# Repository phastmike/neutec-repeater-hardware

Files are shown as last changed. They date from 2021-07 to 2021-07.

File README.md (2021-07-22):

# Guia do projecto Repetidor Neutec

Este documento visa guiar e documentar o projecto Repetidor Neutec.

## Enquadramento

O projecto surge de um contacto informal do Costa (**CT1EYN**) comigo
(**CT1ENQ**), cujo objectivo inicial seria documentar a parte de controlo que o
Costa (**CT4QC**) fez no repetidor de UHF de Guimarães para posteriormente as 
aplicar num repetidor de origem da Neutec que não cumpria os requisitos legais.

Quando referimos o Costa (**CT4QC**), também devemos incluir o Armindo
(**CT1AND**) e outros que eventualmente tenham participado no esforço de munir a
ARM (Associação de Rádioamadores do Minho) de um conjunto de repetidores de
"construção caseira".

Como não privei nem tive grande contacto com os membros da ARM desse período,
além de ter estado ausente da região por vários anos, acabo por desconhecer a
história dos bastidores técnicos da associação. Entretanto, infelizmente, quem 
detinha o conhecimento acabou por falecer (sk).

### Um pouco de história

Através de um documento anexo ao repetidor de Guimarães conseguimos apurar a
data de Setembro 1998 pelo que terá sido por essa altura que o repetidor estaria
pronto para ser instalado. Este repetidor era um rádio Neutec SM-1630U (UHF)
modificado para servir como repetidor. O emissor e receptor funcionam em
simultâneo e essa modificação não foi documentada, nem na altura, nem agora.
Também foi introduzida alguma electrónica para controlo de transmissão, 
identificação em morse com intervalo de 10 minutos entre outros.
Posteriormente, teve nova intervenção para cumprir os novos requisitos de
identificação de voz. Estas adições são o alvo da nossa documentação.

Inicialmente o indicativo do repetidor era **CT0UGM** na frequência de 
**439.100 MHz**, RU88, e com a alteração da legislação, passou a ter o
indicativo **CQ0UGMR**, RU728, até aos dias de hoje.

### O início do projecto

Volvidos estes anos todos e havendo no legado da ARM, um repetidor de origem da
Neutec (SM-1645HS) para os 2m (VHF), operacional mas sem tom de protecção e sem 
identificação, fazia todo o sentido perceber o que foi feito no repetidor de 
Guimarães e replicar, dentro das diferenças existentes, algo similar para dotar
a ARM de um repetidor que pudesse servir de substituto ou mesmo para uma nova
instalação. 

Havendo essa necessidade e com a pandemia que nos afectou desde 2019 até à
actualidade (estamos em 2021) houve um novo fôlego na comunidade de 
rádioaamadores e o Costa (**CT1EYN**) lançou o desafio que foi aceite.

Infelizmente só tivemos acesso ao repetidor Neutec já na fase final do projecto
pelo que haveria lugar a algumas melhorias adicionais, ainda assim, foi obtido
um bom resultado e estamos em testes finais faltando apenas os testes de campo
na montanha da Santa Marta, no local do repetidor.

## Requisitos

Legalmente, em Portugal, um repetidor para o serviço de amador deve cumprir um
conjunto de requisitos. Do ponto de vista de controlo, são os seguintes:

- Tempo de retransmissão - Timeout Timer: Max 3 min (180s)
- Tempo de penalização - Retrigger/Penalty: 5 seg.
- Intervalo de identificação - ID Interval: Max 10 min (600s)

Requisito adicional, será o de evitar que a identificação ocorra quando alguém
está a utilizar o repetidor evitando assim que duas vozes concorram pela atenção
. Além disso deve contemplar a utilização do microfone de mão, no próprio
repetidor e evitar que não haja identificação durante um período de bloqueio
("timeout"). Este requisito levanta uma questão em particular, a da
obrigatoriedade de se identificar de 10 em 10 minutos. No entanto, a lei deve,
na minha opinião, ser entendida ao invés de uma interpretação cega. Assim; 
do ponto de vista da nossa actividade, faz todo o sentido, identificar o
repetidor, intervaladamente, para que eventuais escutas,quando não haja 
actividade no repetidor, consigam identificar o mesmo.
Se a identificação ocorrer em simultâneo com um QSO, em nada será benéfico, 
tanto é que este requisito se coloca. Do ponto de vista informativo, a presença
de um QSO implica a identificação dos intervinientes que por sua vez identifica
indirectamente o repetidor que por sua vez aguardará de forma incessante, a
possibilidade de se identificar, se é que podemos dizê-lo desta forma. Se a 
identificação ocorre no primeiro instante em que está livre ou se após uma
análise mais ou menos cuidada, o resultado obtido, será sempre no intuito de
seguir a lei mas salvaguardando a "qualidade" de um qso.

## Primeira análise

O primeiro passo do projecto foi efectuar engenharia reversa nos circuitos de
controlo construídos pelo Costa (**CT4QC**) por forma a desenhar um esquema e
posterior compreensão dos passos dados na altura. 

O repetidor de Guimarães foi construído com montagem de superfície utilizando
componentes THT, com PCB cortados "à mão" e placas de furos genéricas. Além
disso, estão divididos em dois "conjuntos" que para simplicidade passaremos a
designar por:

- Placa de cima
- Placa de baixo

Esta designação tem em consideração o posicionamente dos circuitos na montagem
original que foi mantida.

### Placa de baixo

Na placa de baixo temos vários blocos:

- Detecção de sub-tom
- Controlo de PTT
- Temporização de cauda
- Temporização de retransmissão

### Placa de cima

Na placa de cima temos os blocos referentes à identificação:

- microcontrolador
 - temporizador de 10min.
 - verificação de tom e ou PTT
 - disparo da identificação Voz/Morse
- controlo de PTT da identificação
- gerador de sinal áudio de Morse

## Organização do projecto

Após esta breve explicação, convém descrever a organização da documentação
relativa ao projecto. 

O projecto é na realidade um conjunto de projectos:

- Desenho dos esquemas do repetidor original
- Novo projecto de repetidor baseado no anterior, inclui PCBs e novo *firmware*
- Adaptação do desenho original, no repetidor de Guimarães com as alterações
realizadas ao esquema inicial.
- Vários (documentos, *datasheets*, imagens, etc)

## Descrição detalhada

Segue uma descrição, mais detalhada, das várias pastas deste projecto.

### [CT1ENQ_CT1EYN](./CT1ENQ_CT1EYN/)

As novas placas, esquemas e firmware.

- [Placa de baixo](./CT1ENQ_CT1EYN/bottom)
- [Placa de cima](./CT1ENQ_CT1EYN/top)
- [Novo firmware e código fonte (AT89C2051)](./CT1ENQ_CT1EYN/firmware)
- [Manual](./CT1ENQ_CT1EYN/manual)

### [CT4QC](./CT4QC)

O esquema original das adições que foram feitas ao SM-1630U para o dotar de
controlo de repetidor (baseado no repetidor de UHF de Guimarães). Também inclui
os esquemas das alterações que foram feitas ao original e uma "imagem" do
código original (binário). O firmware para esta modificação está anexa ao
novo *firmware* do repetidor.

- [Esquema de baixo](./CT4QC/original/bottom)
- [Esquema de cima](./CT4QC/original/top)
- [Esquema das novas modificações (cima)](./CT4QC/mod/)
- [*Firmware* original do AT89C2051](./CT4QC/original/firmware)

#### [Tools](./tools)

Programas auxiliares para cálculo de valores no temporizador e detector de tom.
Contém tabelas de valores em pdf.

#### [Doc](./doc/)
  
Conjunto de documentos reunidos durante o desenrolar do projecto, uns mais
relevantes do que outros (Datasheets, Papers, Pdfs, etc).

**Esta pasta não deverá estar presente nos repositórios públicos**.

#### [Images](./images/)

Imagens relacionadas com o projecto.

**Esta pasta não deverá estar presente nos repositórios públicos**.

#### [Sound](./sound/)

Ficheiros de áudio, utilizados no projecto (identificação).

## Software, *Frameworks* e outras informações

O trabalho foi projectado na sua totalidade num sistema Linux (Fedora 34) no
entanto existem as mesmas ferramentas ou equivalentes para o sistema Windows.

No desenho de esquemas e placas de circuito impresso, foi utilizado o
software gratuito, [KiCad 5.1.10-1](https://www.kicad.org).

O firmware foi desenvolvido em linguagem C e foi utilizado o compilador **sdcc**
, [Small Devices C Compiler](http://sdcc.sourceforge.net/) (v4.0.0) juntamente
com **Makefiles**.

Para programar o microcontrolador AT89C2051, utilizamos o programador
[TL866II Plus](http://www.autoelectric.cn/en/tl866_main.html) e o programa
[**minipro** (linux)](https://gitlab.com/DavidGriffith/minipro/).

## Notas finais

Os projectos devem ter documentos descritivos dentro de cada pasta, sempre que
se justificar.

Também convém indicar que o projecto de firmare (código fonte), quando num
contexto de repositório público, terá o seu repositório próprio. Já os esquemas
e restantes ficheiros estarão a acompanhar este documento. Num contexto interno
à ARM ou da comunidade de rádioamadores local, os ficheiros estarão todos 
agregados, num formato de compressão comum.

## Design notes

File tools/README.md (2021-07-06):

# Tools

Simple programs to list values for timeout timer and ctcss circuits.

## Folders

- bin

 contains the binary files to execute

- src
  
 contains the c source code

- doc

  contains a simple processed output to generate the pdf files via pandoc

## Notes

Check the Makefile content.

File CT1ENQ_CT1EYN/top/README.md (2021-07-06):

# Neutec Repetidor/Repeater

## PCB Assembly and fitting notes

After assembly, Costa's 555 (Motorola) was erratic at best (bad pin connection?). Changed it for a Philips one and problem solved. Repeater was not ungrabbing the PTT line at the end of transmition (id). The PTT sense circuit is very sensible. Adding a 100nf/10nf capacitor at the main J connector (8 pin molex) pin1 (ID_PTT) did improve the result. Also the ISD play auto ptt key up saw the 100uf removed. Probably it's not even needed or if added then a lower value, eventually a ceramic cap would suffice.

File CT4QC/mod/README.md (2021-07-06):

# Repeater Modification

The goal of this document is to describe the modification of the original circuit,
from CT4QC, to include the new desired behaviour introduced by CT1ENQ and CT1EYN.

This new behaviour features:

- Ability to disabled repeater identification (ID),
- Ability to select between Voice ID, Morse ID or no ID (as indicated above),
- Inhibit ID if repeater is in use.

Portuguese law requires that the repeaters have a voice id, every 10 minutes, 
a maximum timeout of 3 minutes (180 seconds) and a 5 seconds retrigger time.

There are various steps which can be followed that will achieve the same result, but
one thing is known,a new firmware must be flashed so we that we have more flexibility
and control.

## Limitations

As we will not build any hardware we must inherit some decisions like:

- ID Trigger not as reset but as input on pin 11 (P3.7)
- XTAL could be changed but lets consider the installed 4MHz.
- PCB is generic so we have limited in space (Keep it simple).

## Cenarios

### Cenario 1

Keep it simple, ignore morse code, avoid connecting/messing the 555 and to avoid
id, simple add a jumper for **`ToneDetector_ID_PTT`** when connecting to the bottom
board.

Also add a diode to NE567 output (pin 8) and check repeater use (common to all
scenarios).

This approach is very simple and is almost a crime not to do a little better if we are
messing with the repeater this deep.

### Cenario 2

Done is good, well done is much better. Add two jumpers (2 bit binary) to have a 4
option combination for ID. eg:

- Both, either one or none

**Optionally** add another jumper for long or short morse id:

- Short is just callsign **(`"de CQ0VBRG"`)**
- Long is Callsign + QTH Locator **(`"de CQ0VBRG IN51MT"`)**

Add a diode to NE567 output (pin 8) and check repeater use.

**A small shorcut is to avoid the long/short morse selection and simply reprogram the
controller if a new message is desired.**

## Changes

Changes to be preformed for **cenario 2**:

1. Remove ground (GND) from pin 19 (P1.7)
 - This pin controls morse id w/o QTH Locator (Short/Long).
 - Convert this or other pin to a jumper to allow selection of long vs short morse id
- New output pin for voice id trigger (ISD_PLAY) (pin 17).
- Resolder NE555 VCC jumper wire (is cut).
- Resolder Morse ID Audio wire (is cut).
- Add 2 jumpers for id type (Morse/CW)
- Add the diode to a input pin. Test connection to NE567 vs ToneDetector opencolector.

These changes are shown in the new schematic for this modification.

The new firmware is also supplied as source code and check the documentation of this
project for more details.

## Work done

On June 3, 2021 we (ct1enq and ct1eyn) preformed the change. The reset button was left
untouched and does not have any function associated. May add that in a future firmware.
Also, no long/short morse ID. The morse volume pot. may need to be changed (rusty?).
The algorithm for repeater use vs ID ~~should~~ was be improved.

## Document

This document is dated from May 2021. Written by CT1ENQ (callsign at gmail for email).

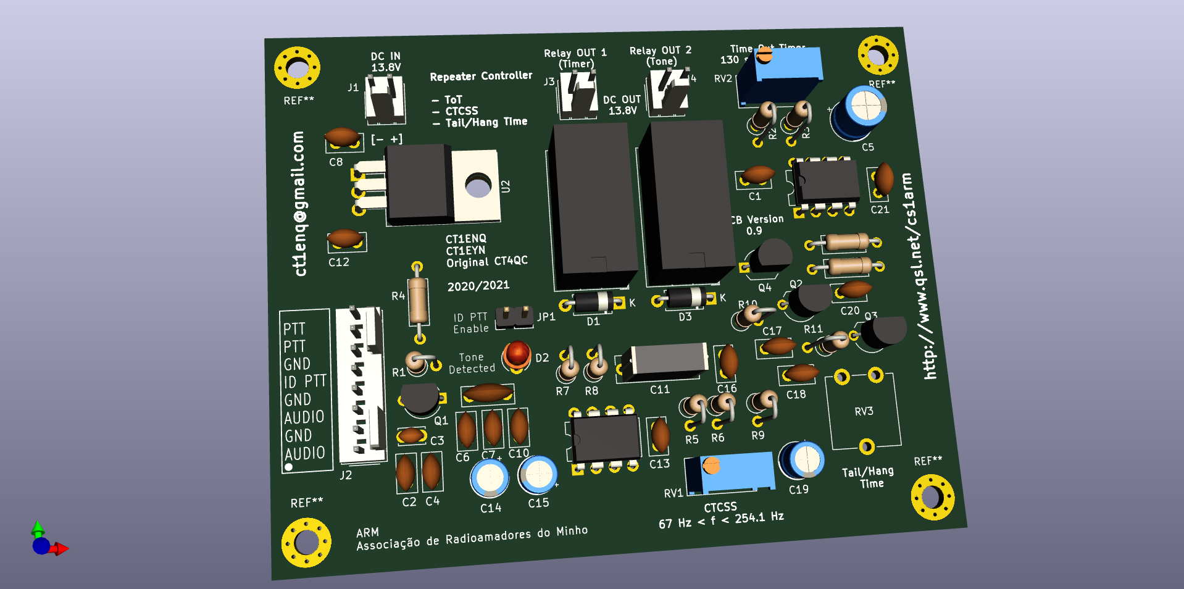
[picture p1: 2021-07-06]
CT1ENQ_CT1EYN/bottom/Export/0.9/RepeaterController3D_V0.9.png

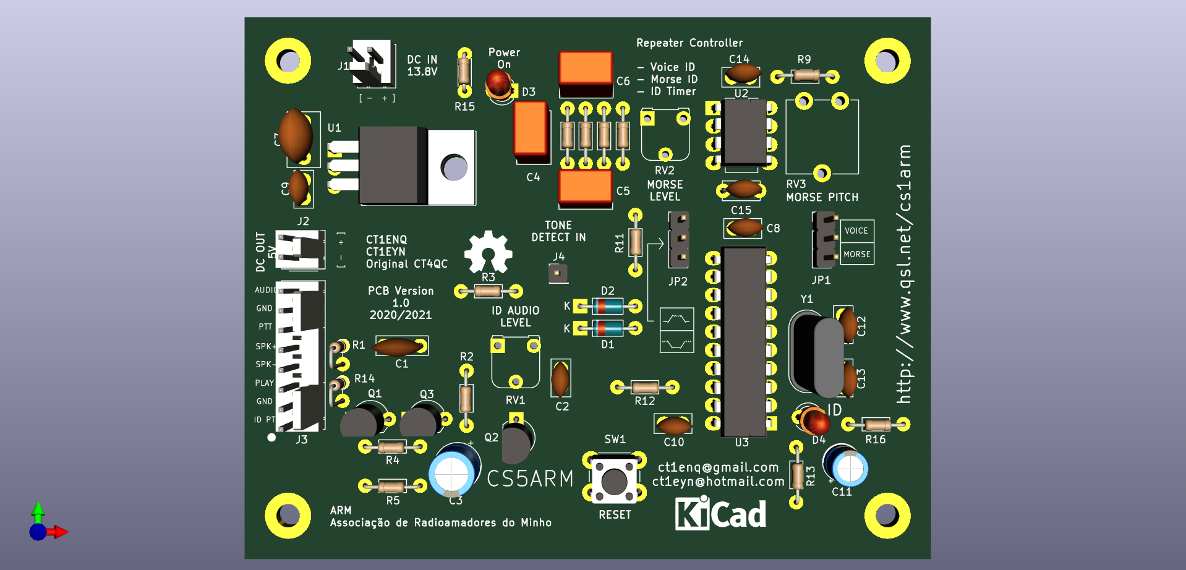
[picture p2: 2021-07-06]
CT1ENQ_CT1EYN/top/Export/1.0/beta/RepeaterController_3d_3.png

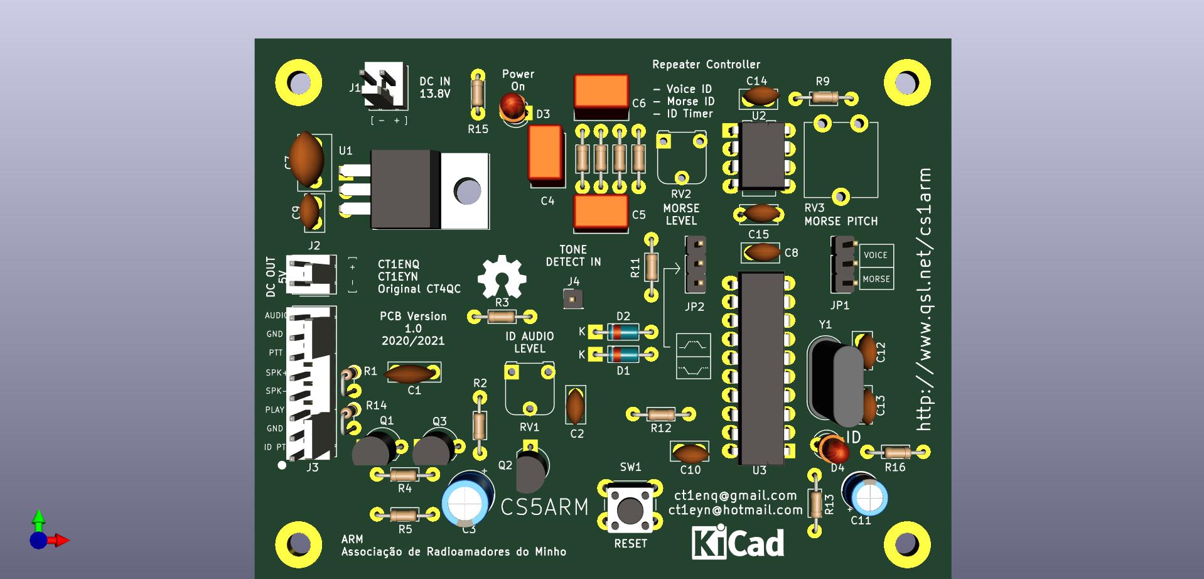
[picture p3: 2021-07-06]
CT1ENQ_CT1EYN/top/Export/1.0/beta/RepeaterController_3d_3.jpg

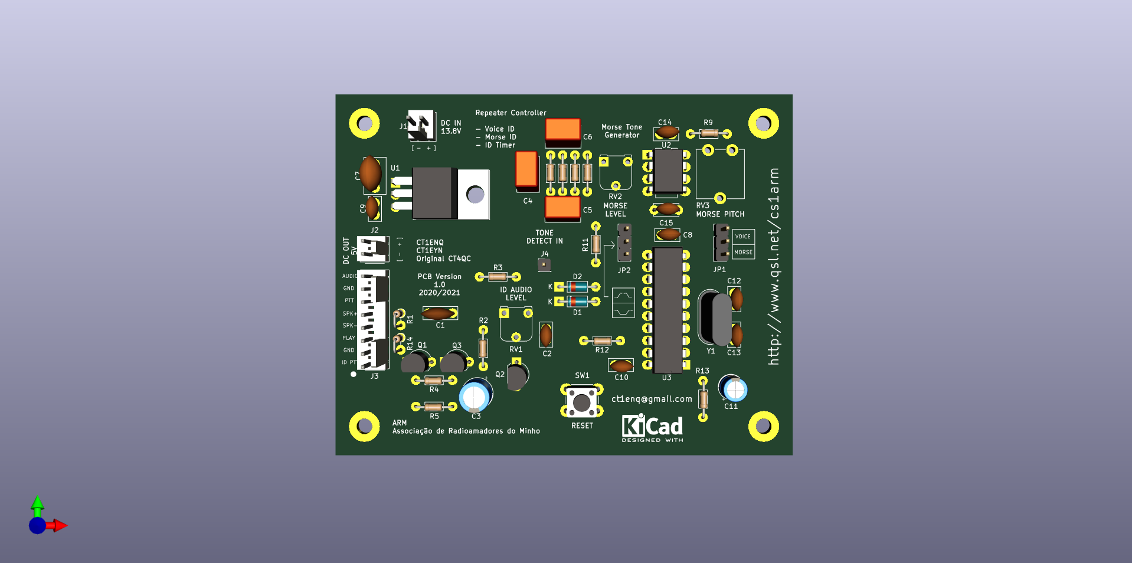
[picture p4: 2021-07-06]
CT1ENQ_CT1EYN/top/Export/1.0/alfa/RepeaterController_3d_1.png

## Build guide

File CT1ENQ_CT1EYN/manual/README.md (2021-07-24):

# Manual Repetidor Neutec SM-1645HS

Pequeno manual das novas funcionalidades e alterações efectuadas ao repetidor
Neutec.

## Placa de baixo

Situada na parte inferior do rádio, a placa de baixo contém o circuito de 
detecção de tom CTCSS (U3), temporizador de *timeout* (U1) e controlo de tempo
de "cauda".

Imagem com identificação das partes a explicar:

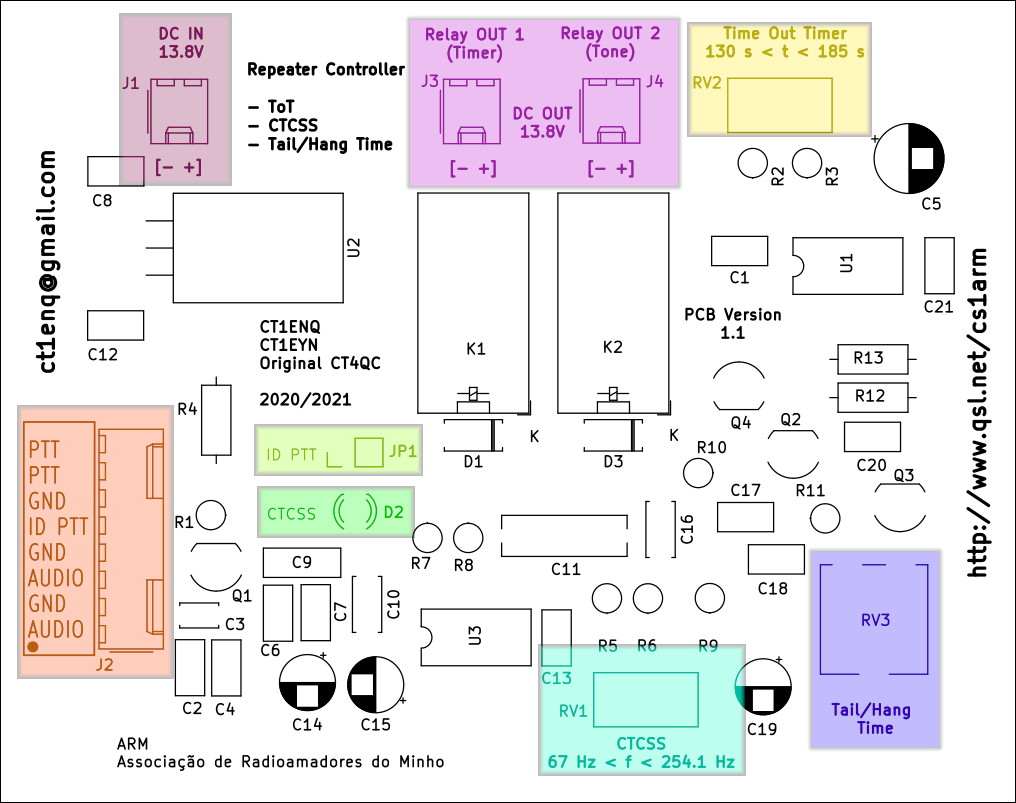
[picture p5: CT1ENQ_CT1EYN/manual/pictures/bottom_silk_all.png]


- **J1**: Alimentação 13.8V (Entrada).
- **J2**: Conjunto de 8 ligações (pino 1 com circulo preto):
 - **8** - **PTT**: Entrada/Saída de PTT
 - **7** - **PTT**: Entrada/Saída de PTT
 - **6** - **GND**: Massa
 - **5** - **ID PTT**: Entrada PTT placa de identificação (ID PTT)
 - **4** - **GND**: Massa
 - **3** - **AUDIO**: Entrada áudio
 - **2** - **GND**: Massa
 - **1** - **AUDIO**: Entrada de áudio
- **J3 e J4**: Saída de 13.8V para as ventoínhas.
 - **J3**: acompanha retransmissão (desliga com *timeout*)
 - **J4**: acompanha presença de CTCSS (mesmo após *timeout*)
- **RV1**: Sintonia do tom CTCSS (afinado para **123 Hz**)
- **RV2**: Tempo de *timeout* (afinado para **180s = 3 min**)
- **RV3**: Tempo de cauda (pequeno ajuste; não se nota muito devido à cauda já 
existente)
- **D2**: Led indica detecção de tom CTCSS
- **JP1**: Se colocado, permite controlo de PTT através da placa de cima (ID).

Em J2, pinos 7 e 8, sinal de PTT, um é utilizado para ligar ao PTT do rádio
e o outro serve para enviar o sinal de PTT para a placa de cima. Os pinos 1 e 3
para entrada/saída de audio aplicavam-se no caso do repetidor de UHF. Aqui basta
utilizar um dos pinos.

## Placa de cima

Situada na parte superior do rádio, a placa de cima contém o circuito de 
identificação do repetidor, controlado por U3 (uC at89c2051). O sinal de áudio
de morse é gerado por U2 (555) e sinal de identificação de voz é gerado por
placa externa com IC da ISD (ISD1820).

Imagem com identificação das partes a explicar:

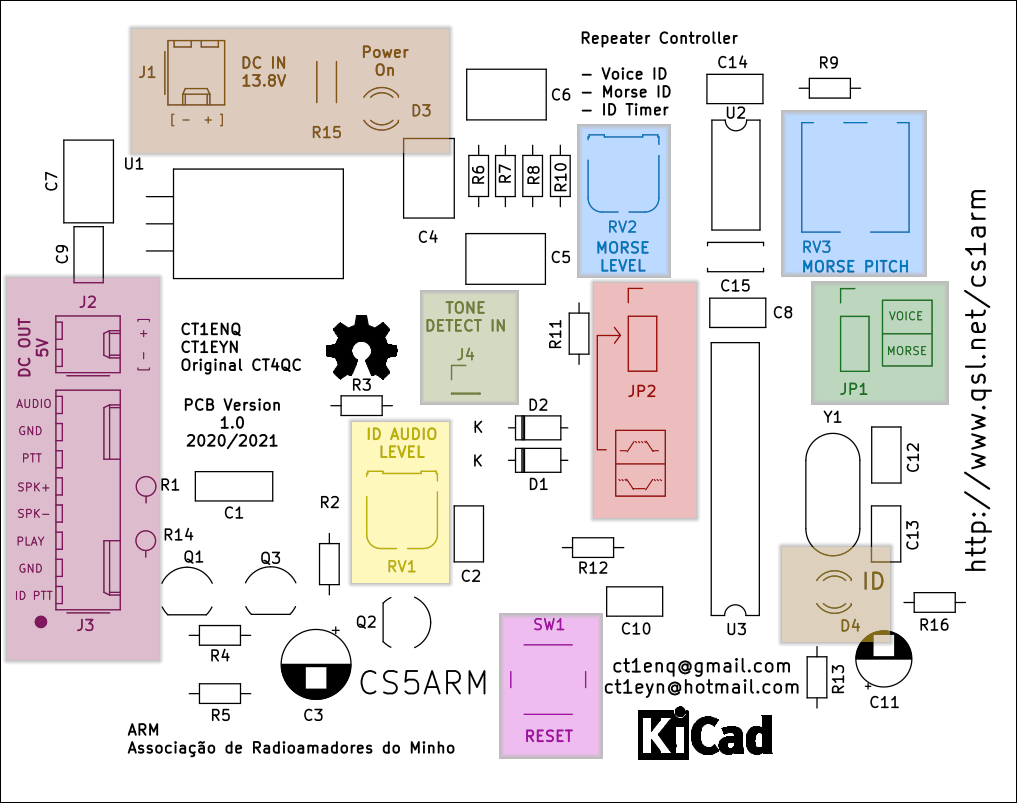
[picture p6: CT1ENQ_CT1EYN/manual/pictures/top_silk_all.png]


- **J1**: Alimentação 13.8V (Entrada)
- **J2**: Saída de 5V para placa de voz (ISD1820)
- **J3**: Conjunto de 8 ligações (pino 1 com círculo preto):
 - **8**: AUDIO: Saída de sinal de áudio, voz e morse
 - **7**: GND: Massa
 - **6**: PTT: Entrada sinal PTT para detectar presença de massa via díodo
 - **5**: SPK+: Entrada *Speaker+* (ISD1820)
 - **4**: SPK-: Entrada *Speaker-* (ISD1820)
 - **3**: PLAY: Saída de disparo/trigger *Play* (ISD1820)
 - **2**: GND: Massa
 - **1**: ID PTT: Saída para controlo PTT quando há identificação
- **J4**: Liga ao relé (Tone) para detectar presença de massa via díodo
- **D3**: Led indica alimentação na placa (depois do regulador U1)
- **D4**: Led para estado de identificação:
 - **Pisca** quando pretende identificar mas não tem jumper JP1 ligado (sem
 tipo de identificação definido)
 - **Ligado** quando está no período de pré identificação, a avaliar utilização
 do repetidor
- **RV3**: *Pitch*/Tom do sinal de morse
- **RV2**: Volume áudio do sinal de morse
- **RV1**: Volume áudio do sinal de Voz (ISD1820)
- **SW1**: *Reset*/Reiniciar microcontrolador
- **JP1**: Selecciona tipo de identificação áudio
 - **1-2** : Voz
 - **2-3** : Morse
- **JP2**: Seleciona tipo de disparo/trigger ISD
 - **1-2**: Transição 0 -> 5 V (Flanco ascendente) (*Default* ISD1820)
 - **2-3**: Transição 5 -> 0 V (Flanco descendente)

## Alterações ao original

O equipamento já era repetidor de origem, embora para tal, era necessário
colocar o *Squelch* no mínimo desligando o interruptor acoplado. O Costa (CT1EYN)
fez um *bypass* e agora **o rádio está sempre em modo repetidor**, 
independentemente da posição do *Squelch* (Indicado pelo Led ***Repeat***).

Dada a natureza do rádio, as alterações necessárias no próprio rádio foram
poucas e pouco intrusivas. Infelizmente o esquema não tinha referências para os
pinos da ficha *J701* (placa do receptor) e foi necessário efectuar esse 
trabalho, apresentado na imagem:

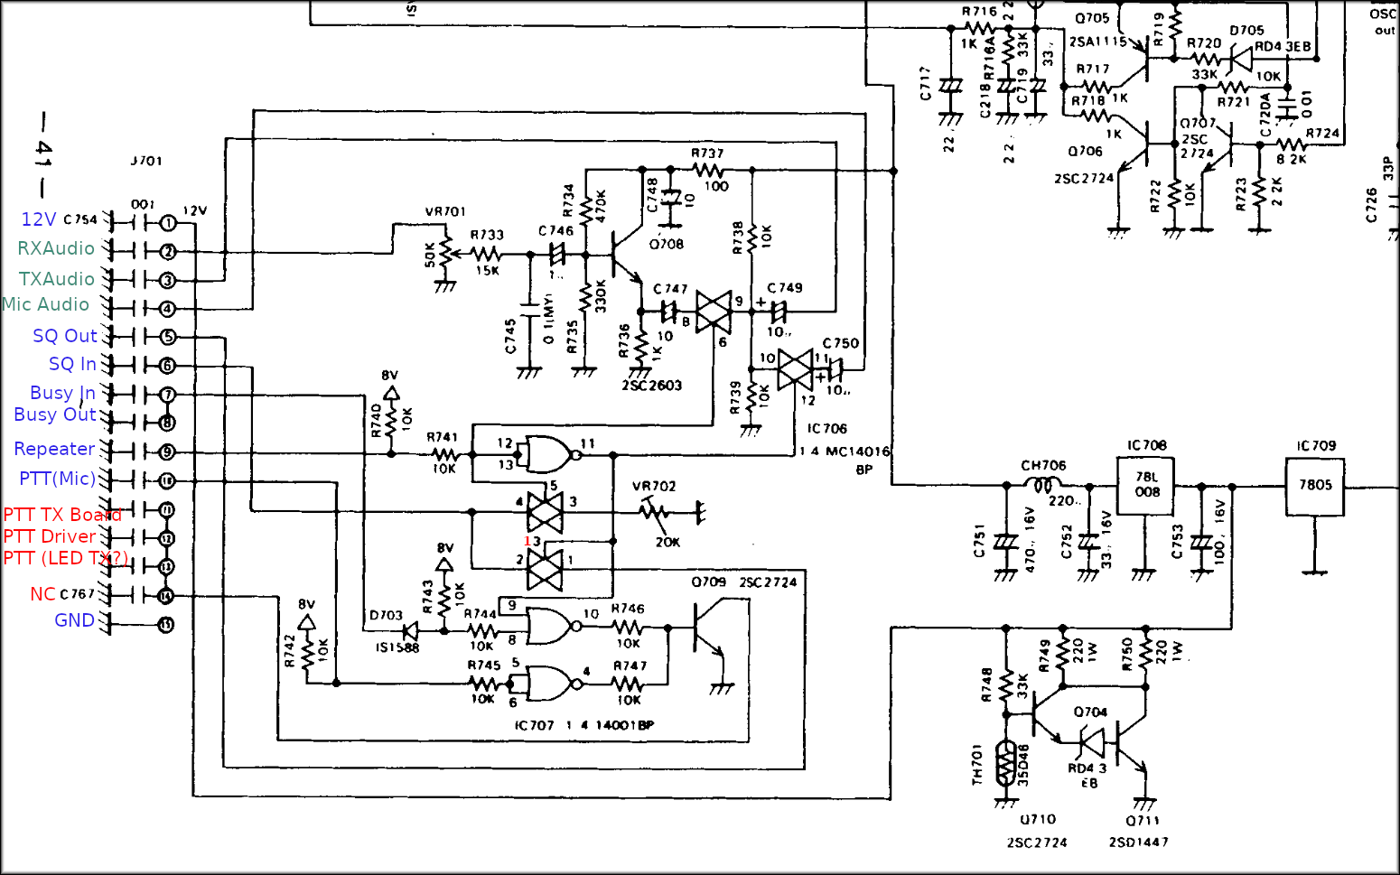
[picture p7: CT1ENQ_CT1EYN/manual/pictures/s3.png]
Neutec J701


Os pinos 11 a 13 (e 14 mas está sem ligação) são o sinal de PTT para o repetidor
original (cores: cinza, branco e azul). Os fios que ligavam a estes pinos, 
juntamente com o pino 10 (violeta - PTT do microfone de mão) foram
redirecionados para uma ficha de 4 pinos que passa a controlar o PTT através da
placa de baixo, representada na figura em baixo no ponto **A**.

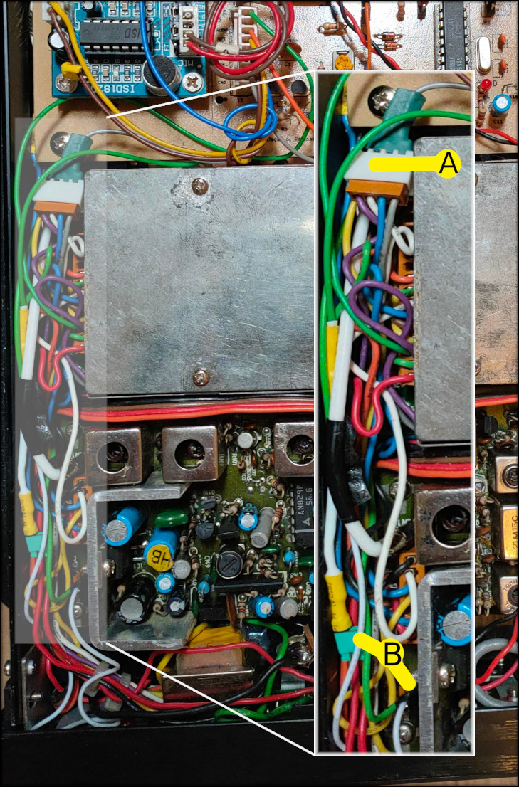
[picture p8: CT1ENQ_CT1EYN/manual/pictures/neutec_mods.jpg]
Neutec Mods


Em **B** está representado o ponto para ir buscar o sinal de áudio ao 
discriminador (J102) ou então ligar a um pino que foi preparado para utilizar a
saída do auscultador externo (com jumper verde), mas aqui o volume passa a
influenciar o sinal que vai para o detector de tom. Quando o sinal está ligado
a este ponto, o volume deve estar na posição indicada na figura:

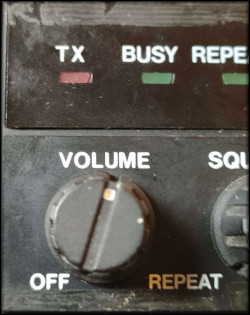
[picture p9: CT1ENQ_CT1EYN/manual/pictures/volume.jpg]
Neutec Volume


O J102 representado no esquema, é o sinal à saída do discriminador e é um
ligador de dois pinos ("*shuntados*").

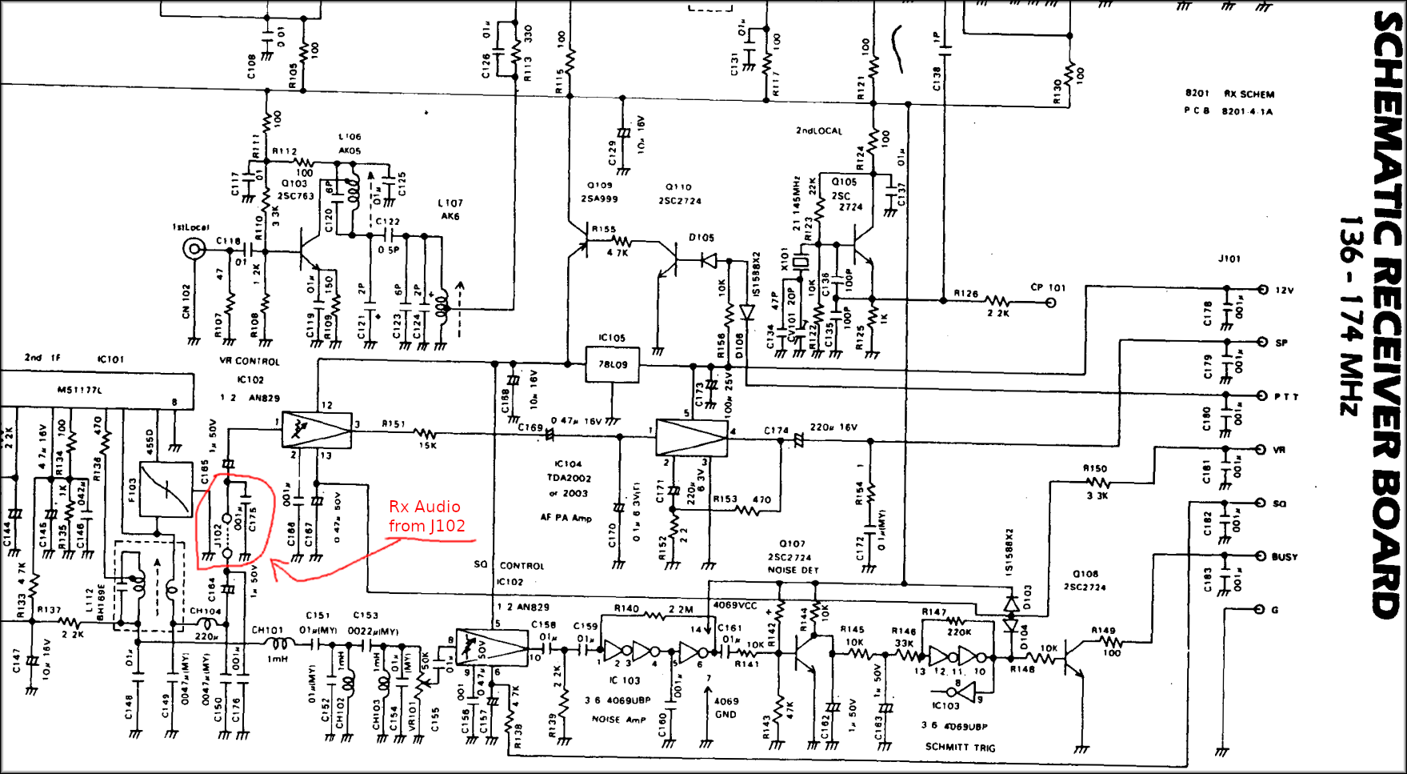
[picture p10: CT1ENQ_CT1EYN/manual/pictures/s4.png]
Neutec J102


O ideal seria utilizar este ponto e evitar a influência do controlo de volume,
no entanto, sinais fracos que nem abrem o limiar do squelch podem colocar o 
repetidor no ar.

## Imagens das placas cima/baixo

### Fundo/Baixo

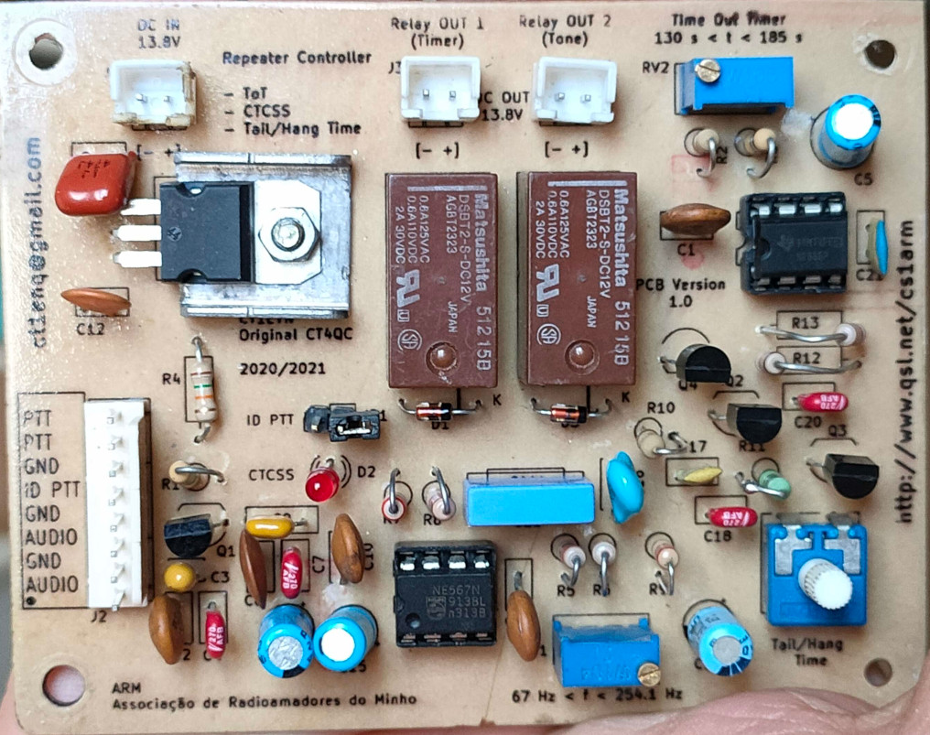
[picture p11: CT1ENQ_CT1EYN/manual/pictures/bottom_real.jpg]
Fundo


### Topo/Cima

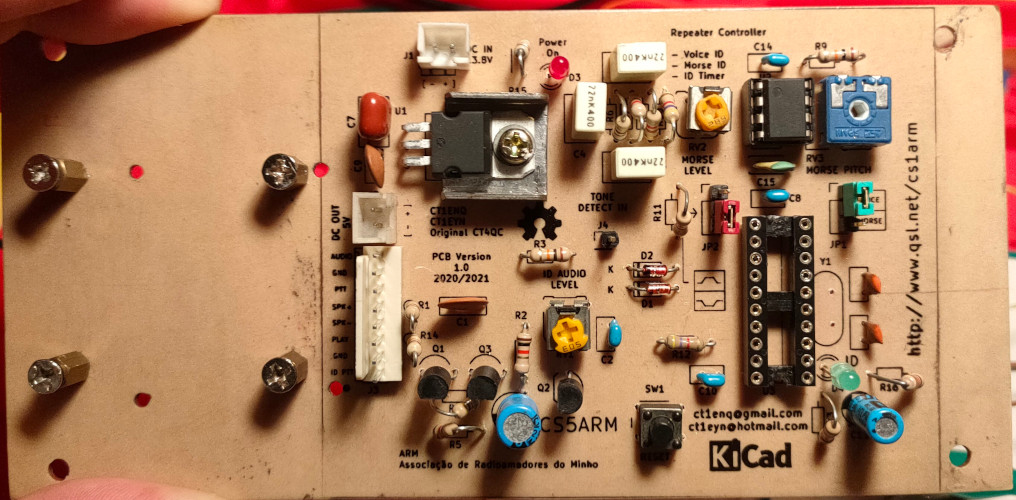
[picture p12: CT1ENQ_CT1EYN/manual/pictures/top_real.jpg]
Topo


## Créditos

2020/2021 Versão 1.1

- CT1ENQ (Miguel) ct1enq@gmail.com
- CT1EYN (Costa) ct1eyn@hotmail.com

##

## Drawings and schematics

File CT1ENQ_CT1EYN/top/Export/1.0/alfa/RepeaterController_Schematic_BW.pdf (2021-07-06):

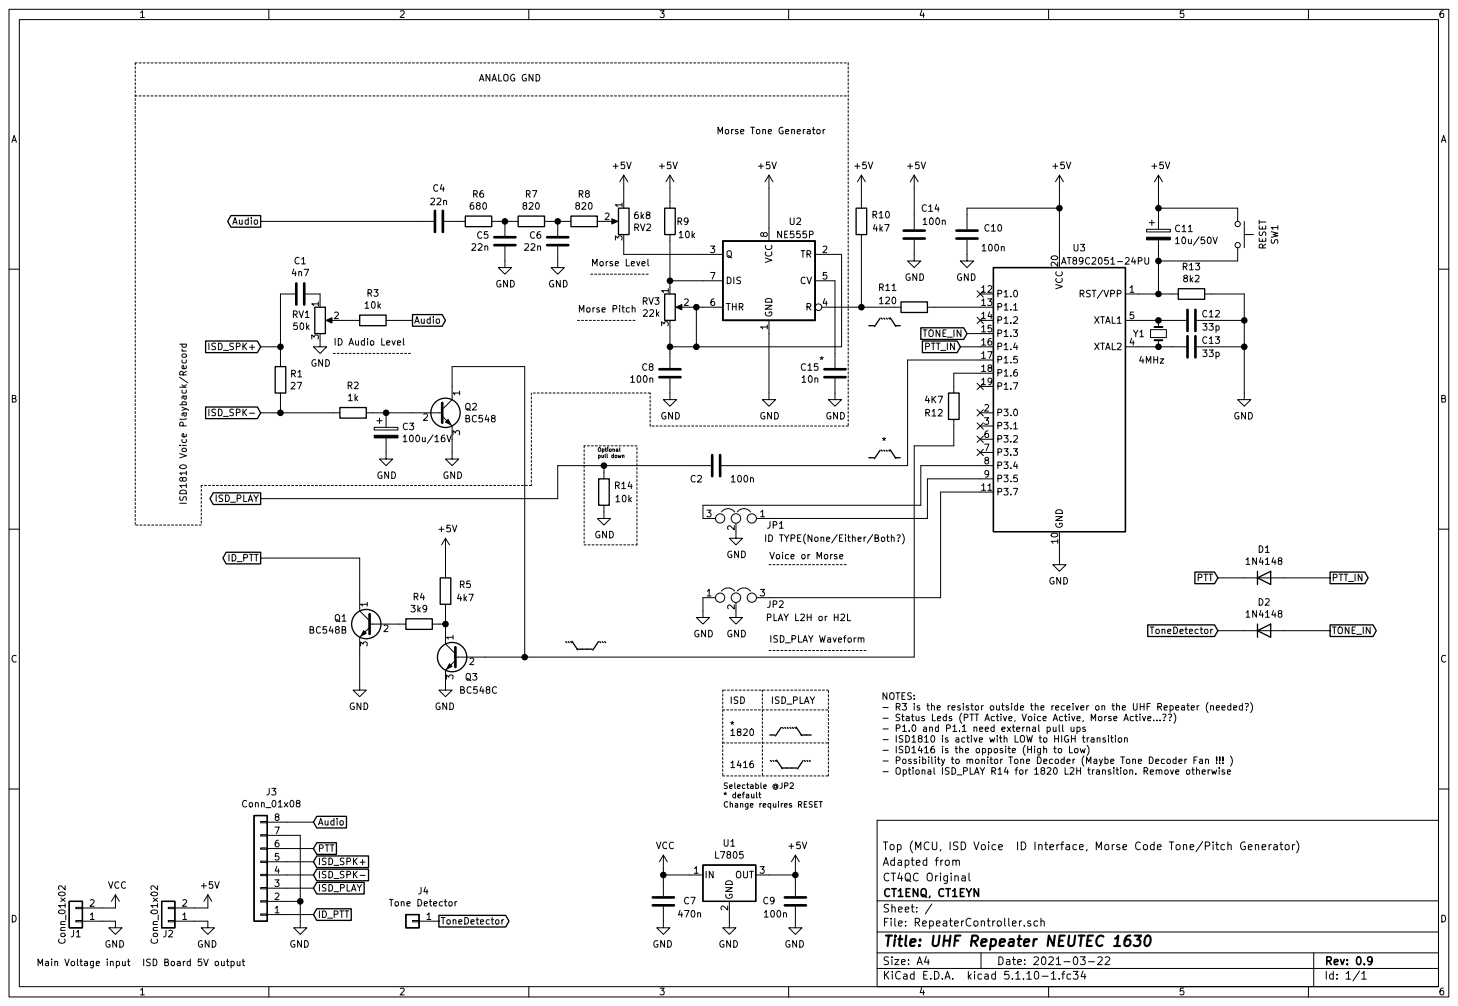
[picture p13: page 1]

- Optional ISD_PLAY R14 for 1820 L2H transition. Remove otherwise Morse Pitch

ID TYPE(None/Either/Both?) R14

ISD ISD_PLAY

- Status Leds (PTT Active, Voice Active, Morse Active...??)
- P1.0 and P1.1 need external pull ups
- ISD1810 is active with LOW to HIGH transition - ISD1416 is the opposite (High to Low)

- Possibility to monitor Tone Decoder (Maybe Tone Decoder Fan !!! )

Top (MCU, ISD Voice ID Interface, Morse Code Tone/Pitch Generator)
Adapted from
CT4QC Original
File: RepeaterController.sch Sheet: / CT1ENQ, CT1EYN

Id: 1/1 Title: UHF Repeater NEUTEC 1630

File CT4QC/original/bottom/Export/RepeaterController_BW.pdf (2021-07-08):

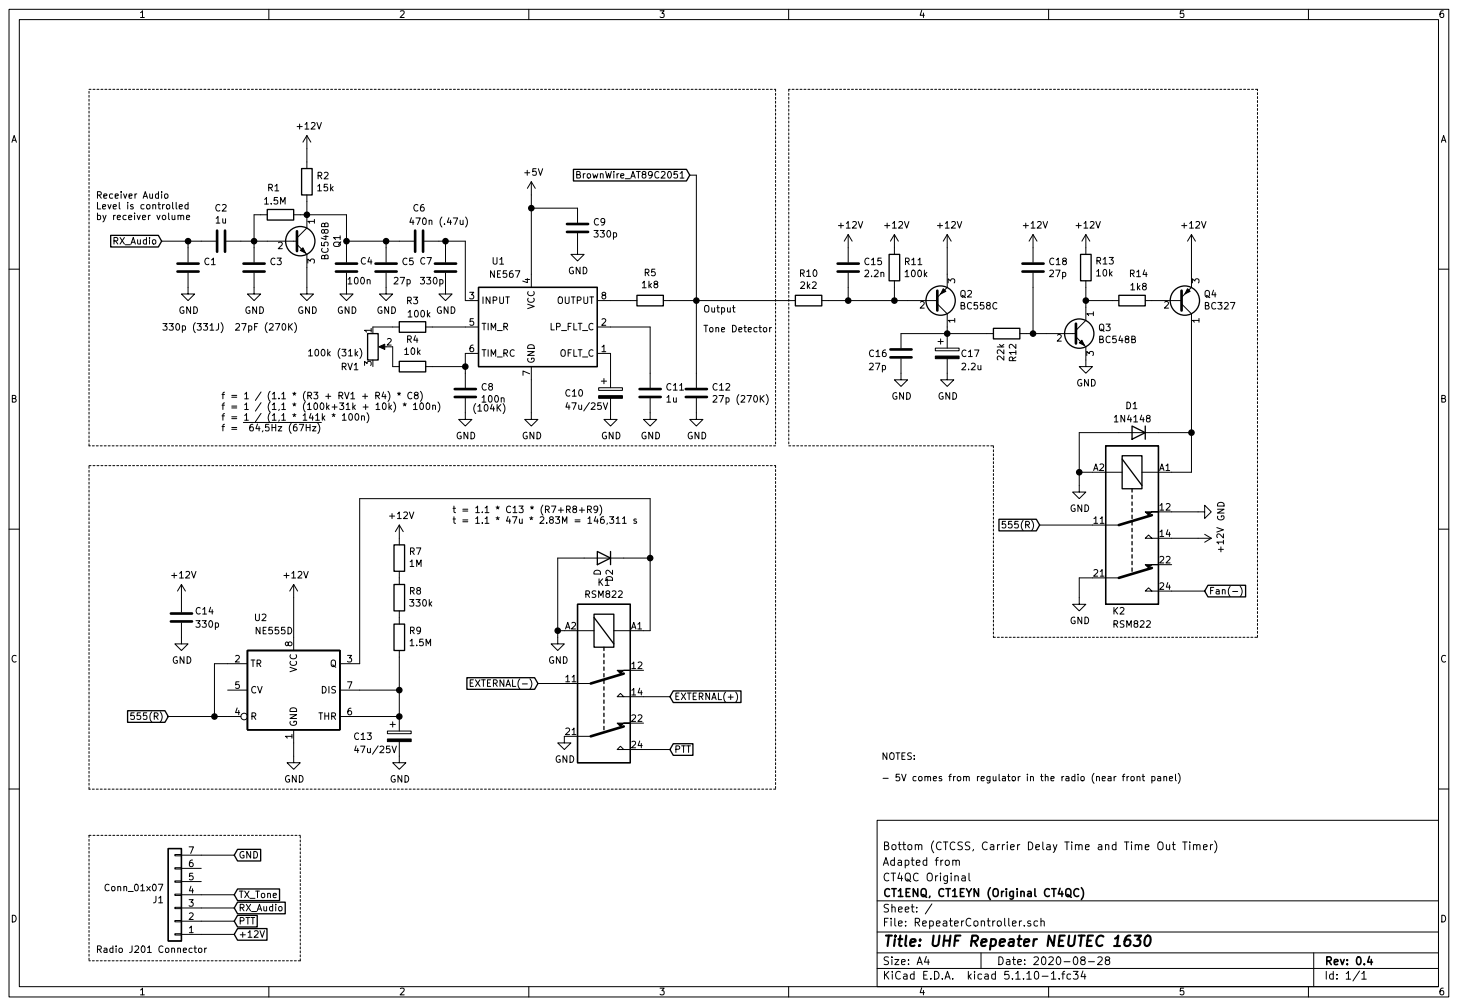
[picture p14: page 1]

Bottom (CTCSS, Carrier Delay Time and Time Out Timer)
Adapted from
CT4QC Original
File: RepeaterController.sch Sheet: / CT1ENQ, CT1EYN (Original CT4QC)

Id: 1/1 Title: UHF Repeater NEUTEC 1630

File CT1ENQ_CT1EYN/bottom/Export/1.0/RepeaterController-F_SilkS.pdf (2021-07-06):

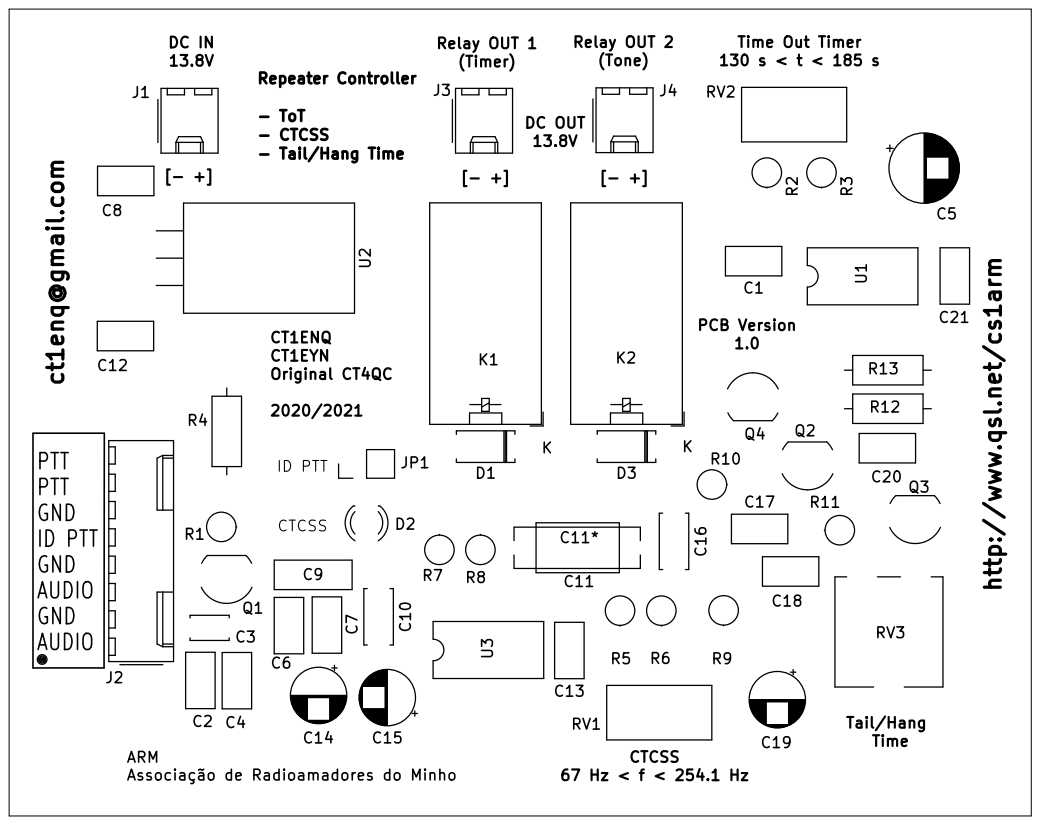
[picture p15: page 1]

67 Hz < f < 254.1 Hz Relay OUT 2

ID PTT ct1enq@gmail.com

http://www.qsl.net/cs1arm PCB Version

Tail/Hang Time ARM

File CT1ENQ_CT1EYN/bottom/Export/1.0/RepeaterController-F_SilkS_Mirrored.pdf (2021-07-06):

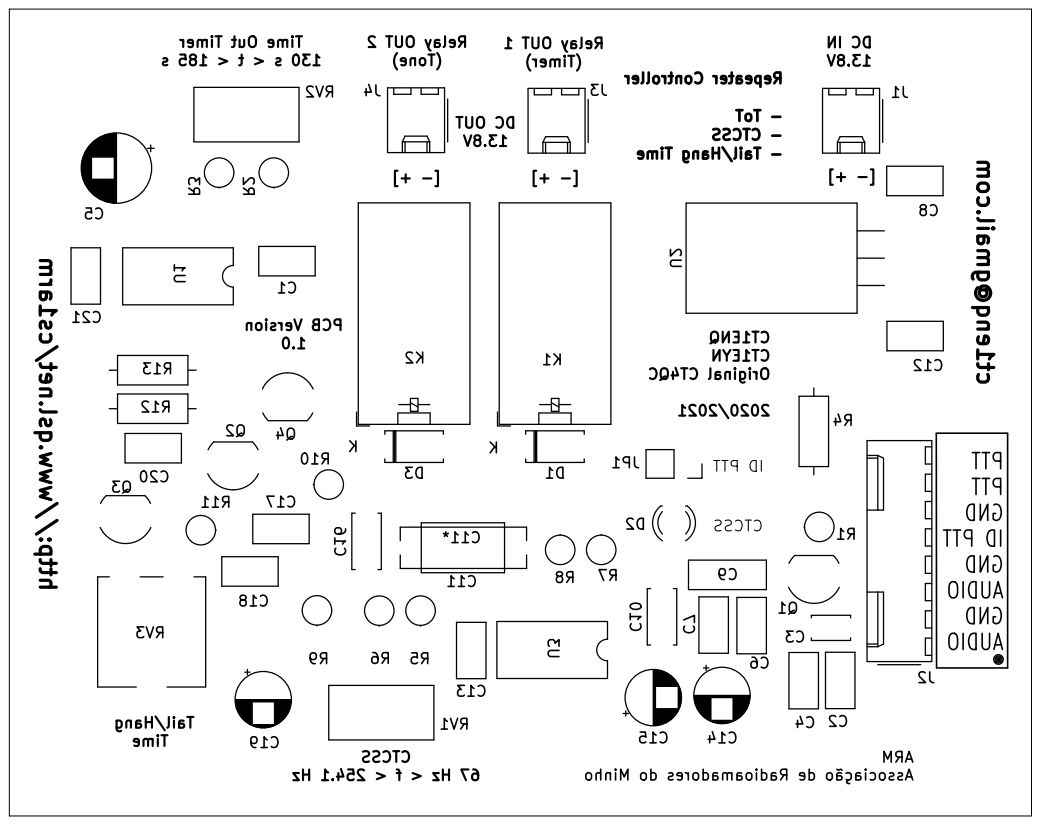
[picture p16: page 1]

(Timer) Time Out Timer 130 s < t < 185 s DC IN

67 Hz < f < 254.1 Hz Relay OUT 2

Associação de Radioamadores do Minho DC OUT

ID PTT ct1enq@gmail.com

http://www.qsl.net/cs1arm PCB Version

Tail/Hang Time ARM

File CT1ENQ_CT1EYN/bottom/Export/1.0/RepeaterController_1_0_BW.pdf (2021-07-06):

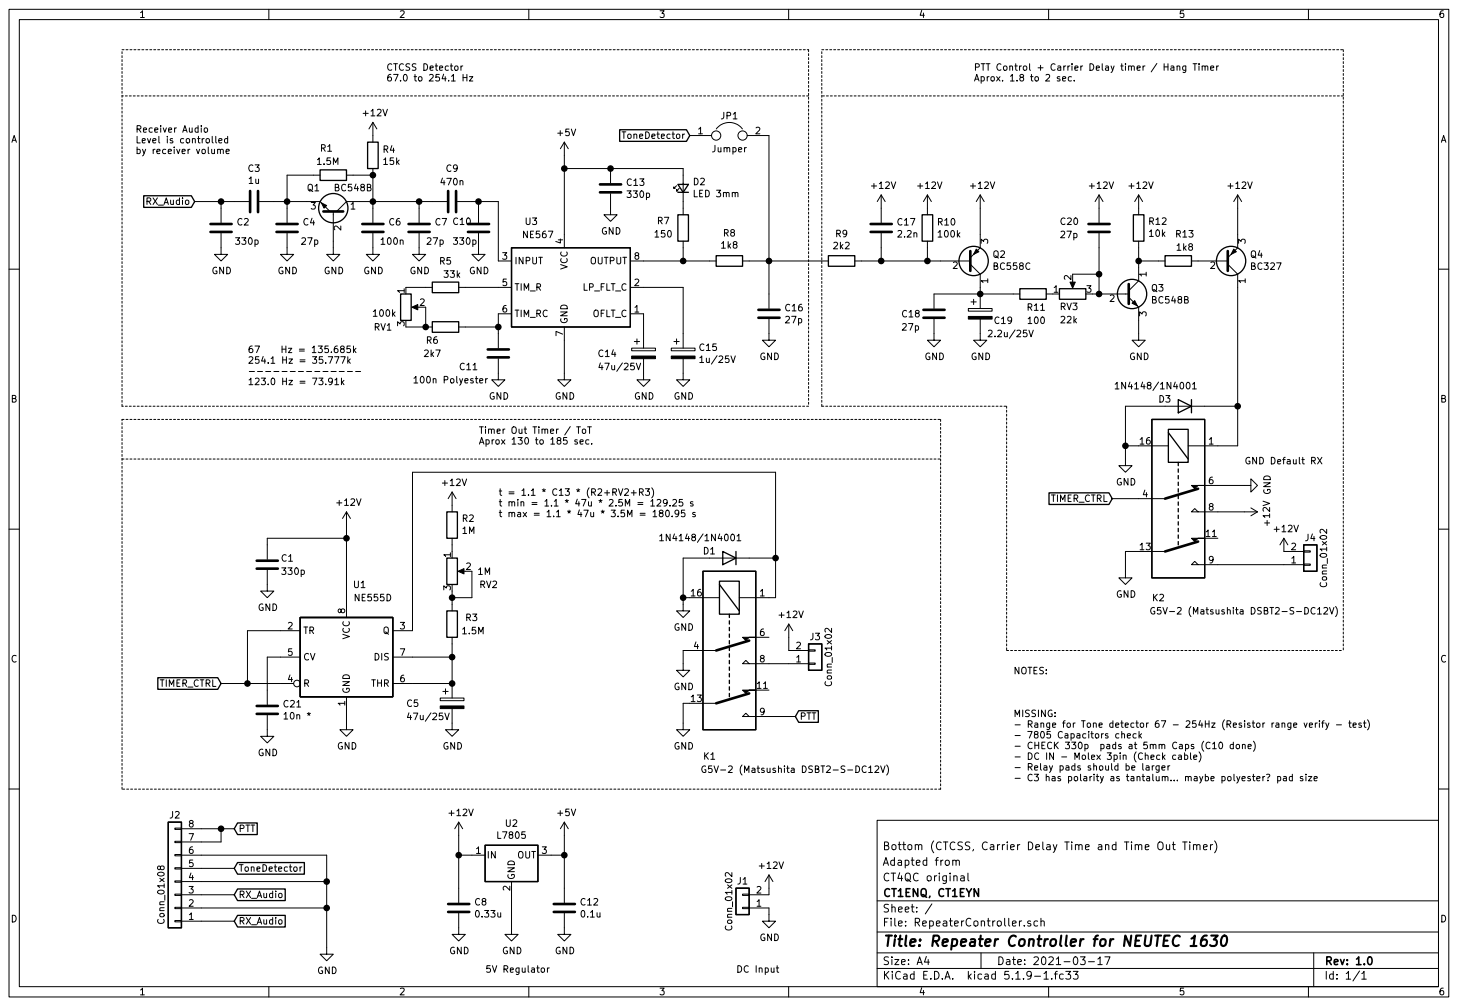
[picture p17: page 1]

CTCSS Detector 67.0 to 254.1 Hz

PTT Control + Carrier Delay timer / Hang Timer

- 7805 Capacitors check
- CHECK 330p pads at 5mm Caps (C10 done)
- DC IN - Molex 3pin (Check cable)
- Relay pads should be larger
- C3 has polarity as tantalum... maybe polyester? pad size

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

Id: 1/1 Title: Repeater Controller for NEUTEC 1630

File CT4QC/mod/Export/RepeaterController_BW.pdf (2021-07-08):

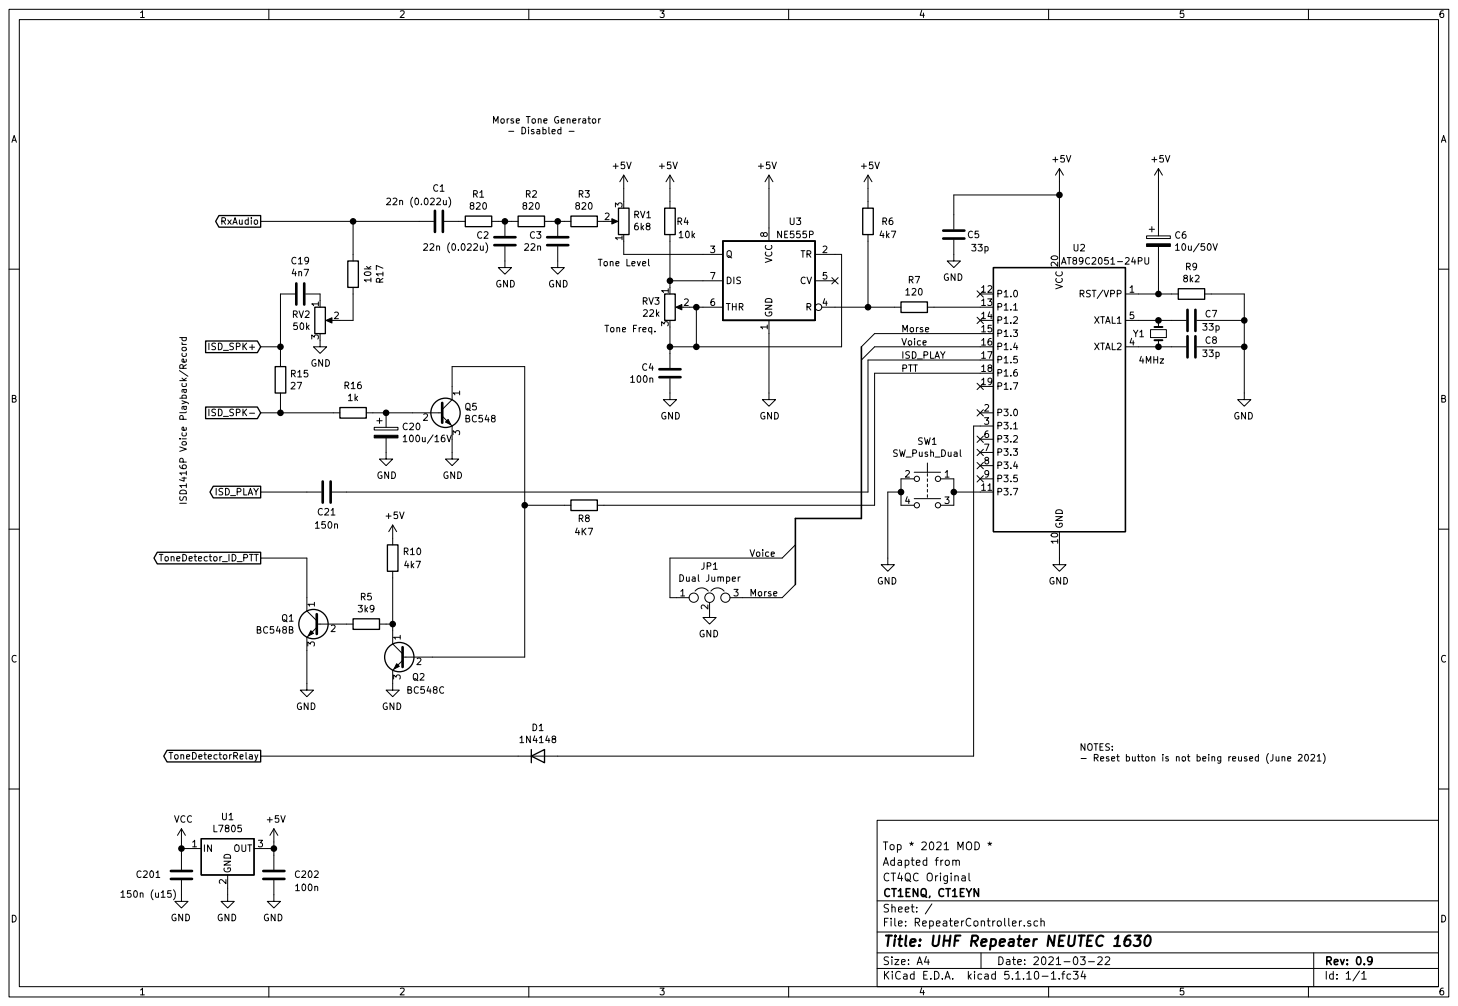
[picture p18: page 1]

- Disabled - ISD1416P Voice Playback/Record

Adapted from
CT4QC Original
File: RepeaterController.sch Sheet: / CT1ENQ, CT1EYN

Id: 1/1 Title: UHF Repeater NEUTEC 1630

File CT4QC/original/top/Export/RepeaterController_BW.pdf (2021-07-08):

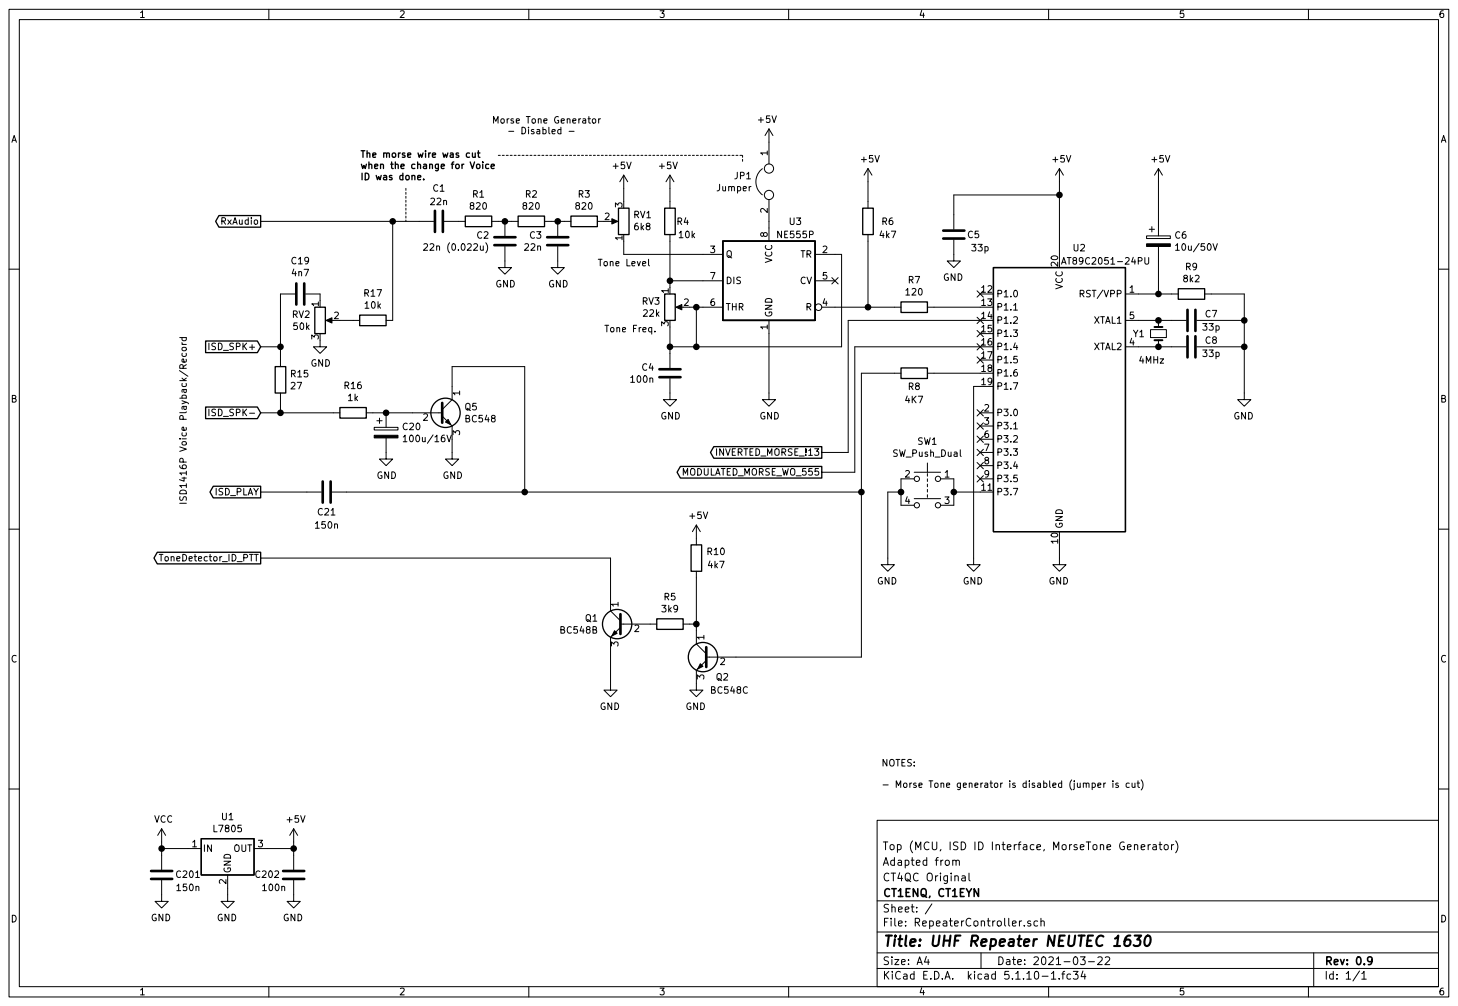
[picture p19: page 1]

Top (MCU, ISD ID Interface, MorseTone Generator)
Adapted from
CT4QC Original
File: RepeaterController.sch Sheet: / CT1ENQ, CT1EYN

Id: 1/1 Title: UHF Repeater NEUTEC 1630

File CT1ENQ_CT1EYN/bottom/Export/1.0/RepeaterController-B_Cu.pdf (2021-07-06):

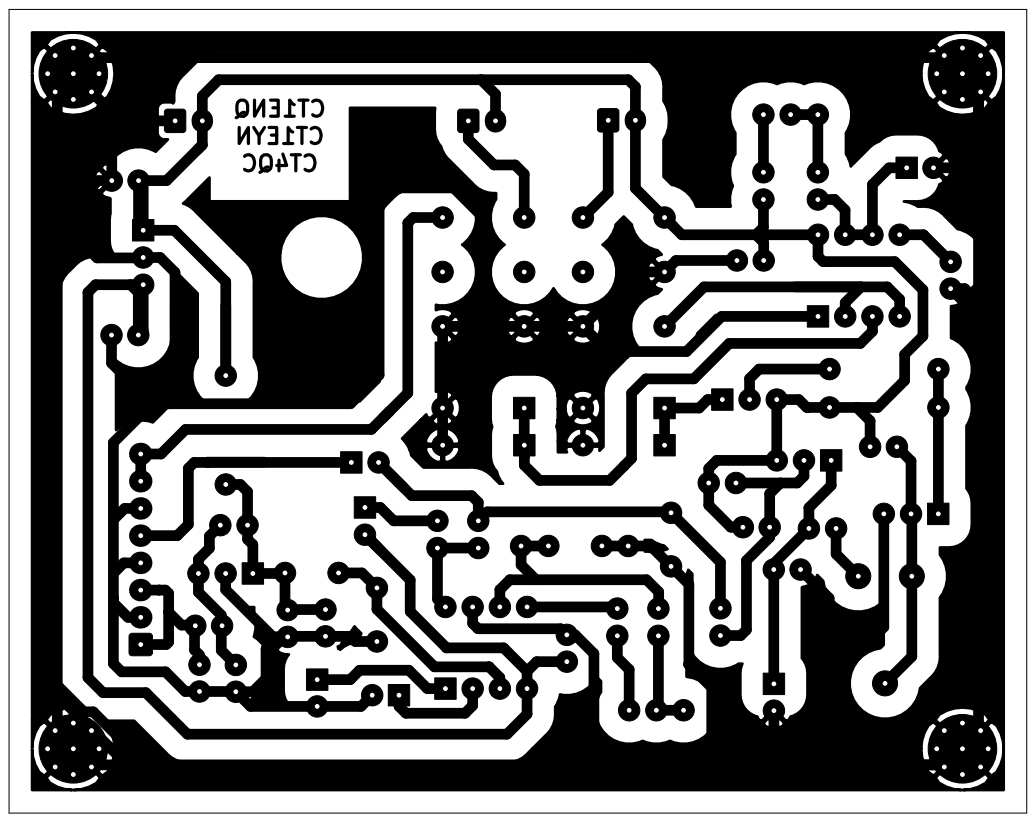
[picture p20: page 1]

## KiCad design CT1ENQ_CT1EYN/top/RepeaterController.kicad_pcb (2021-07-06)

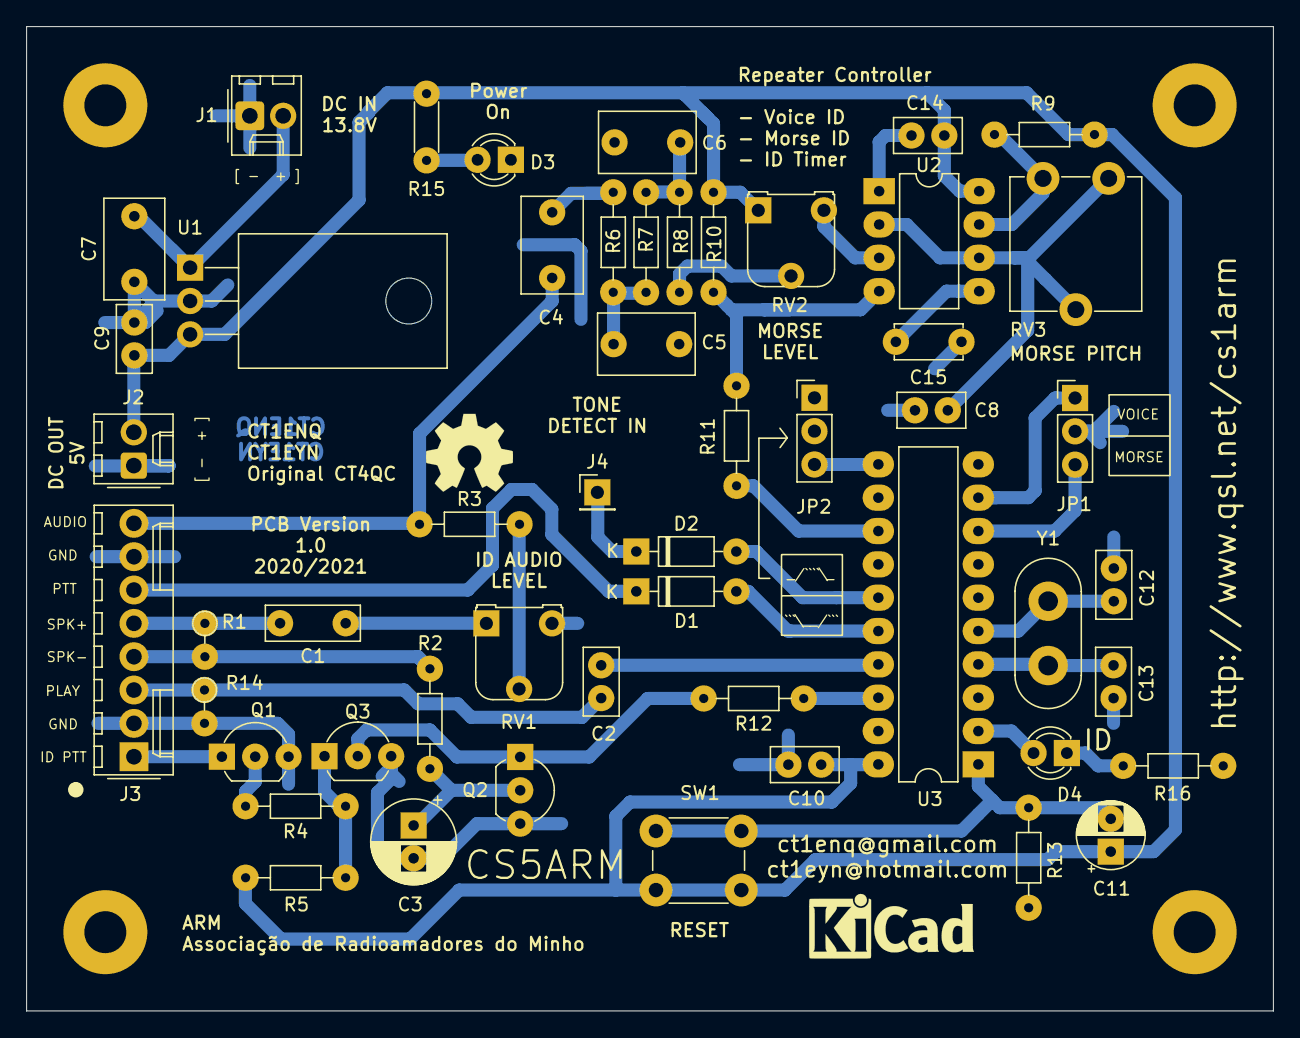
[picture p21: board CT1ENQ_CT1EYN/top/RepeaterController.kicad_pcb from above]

Board: 2 copper layers, 95.0 x 75.0 mm, 52 parts (0 on the bottom side), 39 nets.

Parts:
C1: 4n7; C_Disc_D7.0mm_W2.5mm_P5.00mm
C2, C8, C9, C10, C14: 100n; C_Disc_D5.0mm_W2.5mm_P2.50mm
C3: 100u/16V; CP_Radial_D6.3mm_P2.50mm
C4, C5, C6: 22n; C_Rect_L7.2mm_W4.5mm_P5.00mm_FKS2_FKP2_MKS2_MKP2
C7: 470n; C_Disc_D7.5mm_W4.4mm_P5.00mm
C11: 10u/50V; CP_Radial_D5.0mm_P2.50mm
C12, C13: 33p; C_Disc_D5.0mm_W2.5mm_P2.50mm
C15: 10n; C_Disc_D5.0mm_W2.5mm_P5.00mm
D1, D2: 1N4148; D_DO-35_SOD27_P7.62mm_Horizontal
D3, D4: LED; LED_D3.0mm
J1, J2: Conn_01x02; Molex_KK-254_AE-6410-02A_1x02_P2.54mm_Vertical
J3: Conn_01x08; Molex_KK-254_AE-6410-08A_1x08_P2.54mm_Vertical
J4: Tone Detector; PinHeader_1x01_P2.54mm_Vertical
JP1: ID TYPE(None/Either/Both?); PinHeader_1x03_P2.54mm_Vertical
JP2: PLAY L2H or H2L; PinHeader_1x03_P2.54mm_Vertical
Q1: BC548B; TO-92_Inline_Wide
Q2: BC548; TO-92_Inline_Wide
Q3: BC548C; TO-92_Inline_Wide
R1: 27; R_Axial_DIN0204_L3.6mm_D1.6mm_P2.54mm_Vertical
R2, R16: 1k; R_Axial_DIN0204_L3.6mm_D1.6mm_P7.62mm_Horizontal
R3, R9: 10k; R_Axial_DIN0204_L3.6mm_D1.6mm_P7.62mm_Horizontal
R4: 3k9; R_Axial_DIN0204_L3.6mm_D1.6mm_P7.62mm_Horizontal
R5, R10: 4k7; R_Axial_DIN0204_L3.6mm_D1.6mm_P7.62mm_Horizontal
R6: 680; R_Axial_DIN0204_L3.6mm_D1.6mm_P7.62mm_Horizontal
R7, R8: 820; R_Axial_DIN0204_L3.6mm_D1.6mm_P7.62mm_Horizontal
R11: 120; R_Axial_DIN0204_L3.6mm_D1.6mm_P7.62mm_Horizontal
R12: 4K7; R_Axial_DIN0204_L3.6mm_D1.6mm_P7.62mm_Horizontal
R13: 8k2; R_Axial_DIN0204_L3.6mm_D1.6mm_P7.62mm_Horizontal
R14: 10k; R_Axial_DIN0204_L3.6mm_D1.6mm_P2.54mm_Vertical
R15: 1k; R_Axial_DIN0204_L3.6mm_D1.6mm_P5.08mm_Horizontal
RV1: 50k; Potentiometer_Runtron_RM-065_Vertical
RV2: 6k8; Potentiometer_Runtron_RM-065_Vertical
RV3: 22k; Potentiometer_ACP_CA9-V10_Vertical
SW1: RESET; SW_PUSH_6mm_H4.3mm
U1: L7805; TO-220-3_Horizontal_TabDown
U2: NE555P; DIP-8_W7.62mm_LongPads
U3: AT89C2051-24PU; DIP-20_W7.62mm_LongPads
Y1: 4MHz; Crystal_HC50_Vertical

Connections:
+5V: C9.2, C10.1, C11.1, C14.1, J2.2, R5.1, R9.1, R10.1, R15.1, RV2.1, SW1.2, U1.3, U2.8, U3.20
Audio: C4.1, J3.8, R3.1
GND: C3.2, C5.2, C6.2, C7.1, C8.2, C9.1, C10.2, C12.2, C13.2, C14.2, C15.2, D3.1, J1.1, J2.1, J3.2, J3.7, JP1.2, JP2.1, JP2.2, Q1.3, Q2.3, Q3.3, R13.2, R14.2, R16.2, RV1.3, U1.2, U2.1, U3.10
ID_PTT: J3.1, Q1.1
ISD_PLAY: C2.2, J3.3, R14.1
ISD_SPK+: C1.2, J3.5, R1.1
ISD_SPK-: J3.4, R1.2, R2.2
unnamed: C1.1, RV1.1
unnamed: C2.1, U3.17
unnamed: C3.1, Q2.2, R2.1
unnamed: C4.2, R6.1
unnamed: C5.1, R6.2, R7.1
unnamed: C6.1, R7.2, R8.1
unnamed: C8.1, RV3.2, RV3.3, U2.2, U2.6
unnamed: C11.2, R13.1, SW1.1, U3.1
unnamed: C12.1, U3.5, Y1.1
unnamed: C13.1, U3.4, Y1.2
unnamed: C15.1, U2.5
unnamed: D3.2, R15.2
unnamed: D4.1, R16.1
unnamed: D4.2, U3.2
unnamed: JP1.1, U3.9
unnamed: JP1.3, U3.8
unnamed: JP2.3, U3.11
unnamed: Q1.2, R4.2
unnamed: Q2.1, Q3.2, R12.2
unnamed: Q3.1, R4.1, R5.2
unnamed: R3.2, RV1.2
unnamed: R8.2, RV2.2
unnamed: R9.2, RV3.1, U2.7
unnamed: R10.2, R11.1, U2.4
unnamed: R11.2, U3.13
unnamed: R12.1, U3.18
unnamed: RV2.3, U2.3
PTT: D1.1, J3.6
PTT_IN: D1.2, U3.16
TONE_IN: D2.2, U3.15
ToneDetector: D2.1, J4.1
VCC: C7.2, J1.2, U1.1

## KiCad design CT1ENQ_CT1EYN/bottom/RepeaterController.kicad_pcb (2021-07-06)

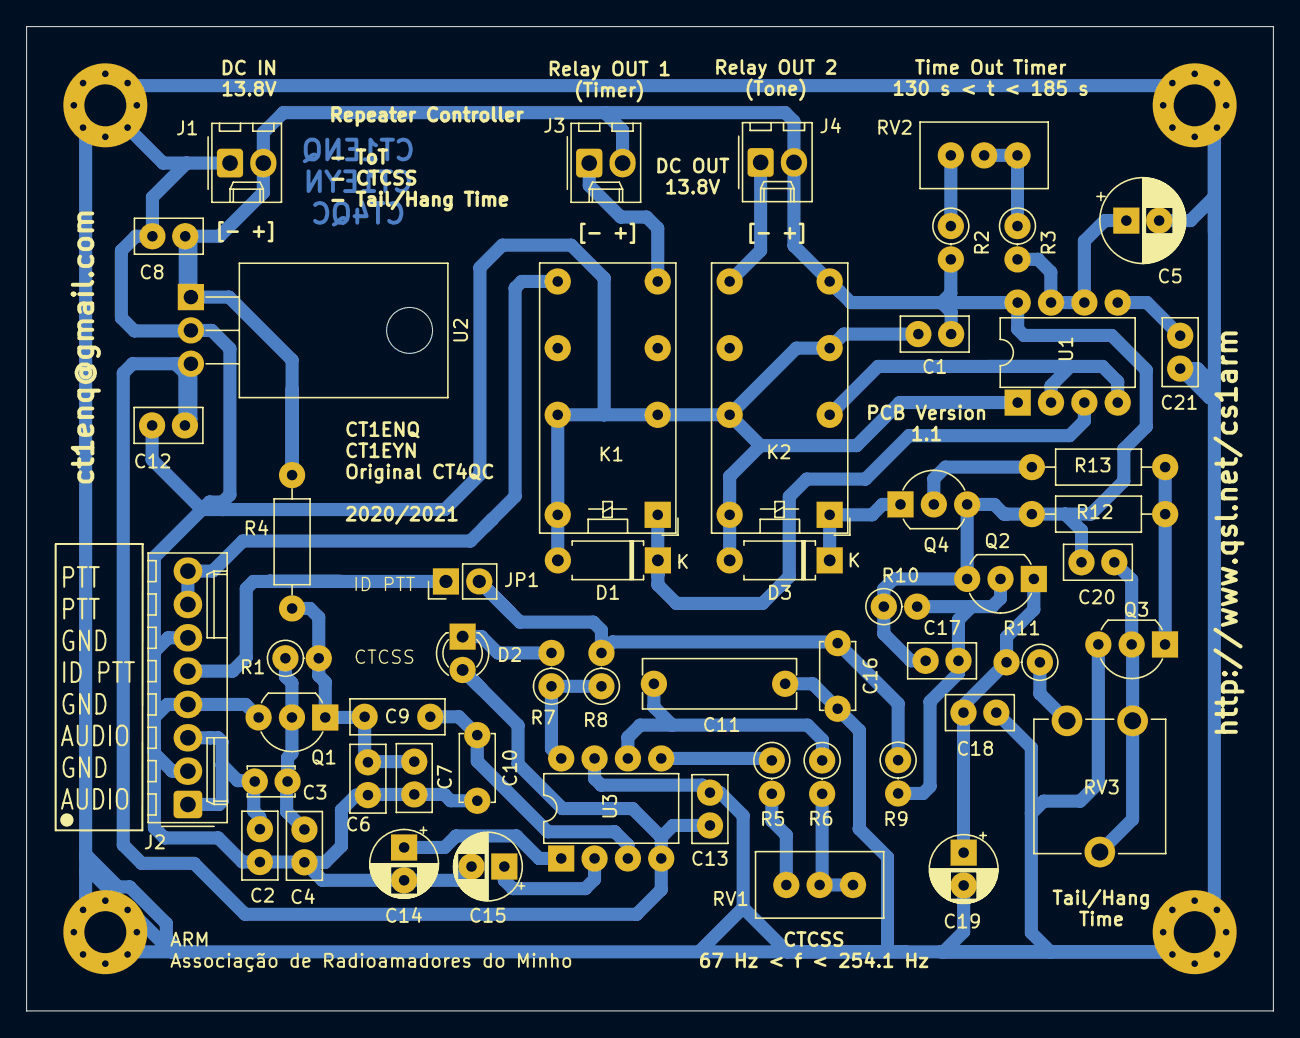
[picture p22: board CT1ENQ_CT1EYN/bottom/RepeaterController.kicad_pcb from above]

Board: 2 copper layers, 95.0 x 75.0 mm, 54 parts (0 on the bottom side), 33 nets.

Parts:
C1, C2, C13: 330p; C_Disc_D5.0mm_W2.5mm_P2.50mm
C3: 1u; C_Disc_D3.4mm_W2.1mm_P2.50mm
C4, C7, C18, C20: 27p; C_Disc_D5.0mm_W2.5mm_P2.50mm
C5: 47u/25V; CP_Radial_D6.3mm_P2.50mm
C6: 100n; C_Disc_D5.0mm_W2.5mm_P2.50mm
C8: 0.33u; C_Disc_D5.0mm_W2.5mm_P2.50mm
C9: 470n; C_Disc_D7.0mm_W2.5mm_P5.00mm
C10: 330p; C_Disc_D5.0mm_W2.5mm_P5.00mm
C11: 100n Polyester; C_Rect_L11.5mm_W3.6mm_P10.00mm_MKT
C12: 0.1u; C_Disc_D5.0mm_W2.5mm_P2.50mm
C14: 47u/25V; CP_Radial_D5.0mm_P2.50mm
C15: 1u/25V; CP_Radial_D5.0mm_P2.50mm
C16: 27p; C_Disc_D5.0mm_W2.5mm_P5.00mm
C17: 2.2n; C_Disc_D5.0mm_W2.5mm_P2.50mm
C19: 2.2u/25V; CP_Radial_D5.0mm_P2.50mm
C21: 10n *; C_Disc_D5.0mm_W2.5mm_P2.50mm
D1, D3: 1N4148/1N4001; D_A-405_P7.62mm_Horizontal
D2: LED 3mm; LED_D3.0mm
J1, J3, J4: Conn_01x02; Molex_KK-254_AE-6410-02A_1x02_P2.54mm_Vertical
J2: Conn_01x08; Molex_KK-254_AE-6410-08A_1x08_P2.54mm_Vertical
JP1: Jumper; PinHeader_1x02_P2.54mm_Vertical
K1, K2: G5V-2 (Matsushita DSBT2-S-DC12V); Relay_DPDT_Omron_G5V-2
Q1, Q3: BC548B; TO-92_Inline_Wide
Q2: BC558C; TO-92_Inline_Wide
Q4: BC327; TO-92_Inline_Wide
R1, R3: 1.5M; R_Axial_DIN0207_L6.3mm_D2.5mm_P2.54mm_Vertical
R2: 1M; R_Axial_DIN0207_L6.3mm_D2.5mm_P2.54mm_Vertical
R4: 15k; R_Axial_DIN0207_L6.3mm_D2.5mm_P10.16mm_Horizontal
R5: 33k; R_Axial_DIN0207_L6.3mm_D2.5mm_P2.54mm_Vertical
R6: 2k7; R_Axial_DIN0207_L6.3mm_D2.5mm_P2.54mm_Vertical
R7: 150; R_Axial_DIN0207_L6.3mm_D2.5mm_P2.54mm_Vertical
R8: 1k8; R_Axial_DIN0207_L6.3mm_D2.5mm_P2.54mm_Vertical
R9: 2k2; R_Axial_DIN0207_L6.3mm_D2.5mm_P2.54mm_Vertical
R10: 100k; R_Axial_DIN0207_L6.3mm_D2.5mm_P2.54mm_Vertical
R11: 100; R_Axial_DIN0207_L6.3mm_D2.5mm_P2.54mm_Vertical
R12: 10k; R_Axial_DIN0207_L6.3mm_D2.5mm_P10.16mm_Horizontal
R13: 1k8; R_Axial_DIN0207_L6.3mm_D2.5mm_P10.16mm_Horizontal
RV1: 100k; Potentiometer_Bourns_3296W_Vertical
RV2: 1M; Potentiometer_Bourns_3296W_Vertical
RV3: 22k; Potentiometer_ACP_CA9-V10_Vertical
U1: NE555D; DIP-8_W7.62mm
U2: L7805; TO-220-3_Horizontal_TabDown
U3: NE567; DIP-8_W7.62mm

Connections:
+5V: C12.1, C13.1, D2.2, U2.3, U3.4
+12V: C1.1, C8.1, C17.1, C20.1, J1.2, J3.2, J4.2, K2.8, Q2.3, Q4.3, R2.2, R4.1, R10.1, R12.2, U1.8, U2.1
GND: C1.2, C2.2, C4.2, C5.2, C6.2, C7.2, C8.2, C10.2, C11.2, C12.2, C13.2, C14.2, C15.2, C16.2, C18.2, C19.2, C21.2, D1.2, D3.2, J1.1, J2.2, J2.4, J2.6, K1.4, K1.13, K1.16, K2.6, K2.13, K2.16, Q1.3, Q3.3, U1.1, U2.2, U3.7
unnamed: C3.1, C4.1, Q1.2, R1.1
unnamed: C5.1, R3.2, U1.6, U1.7
unnamed: C6.1, C7.1, C9.2, Q1.1, R1.2, R4.2
unnamed: C9.1, C10.1, U3.3
unnamed: C11.1, R6.1, U3.6
unnamed: C14.1, U3.1
unnamed: C15.1, U3.2
unnamed: C16.1, JP1.2, R8.2, R9.1
unnamed: C17.2, Q2.2, R9.2, R10.2
unnamed: C18.1, C19.1, Q2.1, R11.2
unnamed: C20.2, Q3.2, RV3.2, RV3.3
unnamed: C21.1, U1.5
unnamed: D1.1, K1.1, U1.3
unnamed: D2.1, R7.2
unnamed: D3.1, K2.1, Q4.1
unnamed: J3.1, K1.8
unnamed: J4.1, K2.9
unnamed: Q3.1, R12.1, R13.1
unnamed: Q4.2, R13.2
unnamed: R2.1, RV2.1
unnamed: R3.1, RV2.2, RV2.3
unnamed: R5.1, U3.5
unnamed: R5.2, RV1.1
unnamed: R6.2, RV1.2, RV1.3
unnamed: R7.1, R8.1, U3.8
unnamed: R11.1, RV3.1
PTT: J2.7, J2.8, K1.9
RX_Audio: C2.1, C3.2, J2.1, J2.3
TIMER_CTRL: K2.4, U1.2, U1.4
ToneDetector: J2.5, JP1.1
